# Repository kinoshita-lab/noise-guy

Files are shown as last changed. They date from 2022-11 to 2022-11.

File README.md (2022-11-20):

# noise-guy kit

[Document in Japanese](README_ja.md)

Tiny white noise generator made by ATTiny10

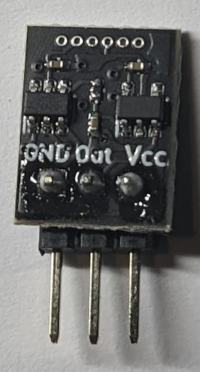
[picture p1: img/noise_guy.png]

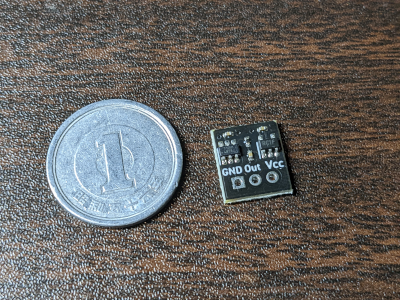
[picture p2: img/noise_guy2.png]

# Kit contents

- Pre-assembled/programmed circuit board
- 1x3 pin vertical header

# How to assemble

Solder the 1x3 pin.

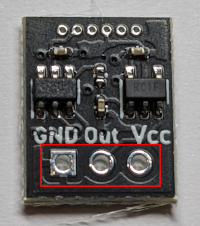
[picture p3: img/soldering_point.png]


# How to use

- Connect power source. This product use ATTiny10 with 8MHz configuration. Vcc must be within the range between 2.7V - 5.5V(cf. ATtiny10 datasheet)
- Add DC Cut capacitor to "Out" terminal externally, to meet your specification(typically 100uF - 470uF).

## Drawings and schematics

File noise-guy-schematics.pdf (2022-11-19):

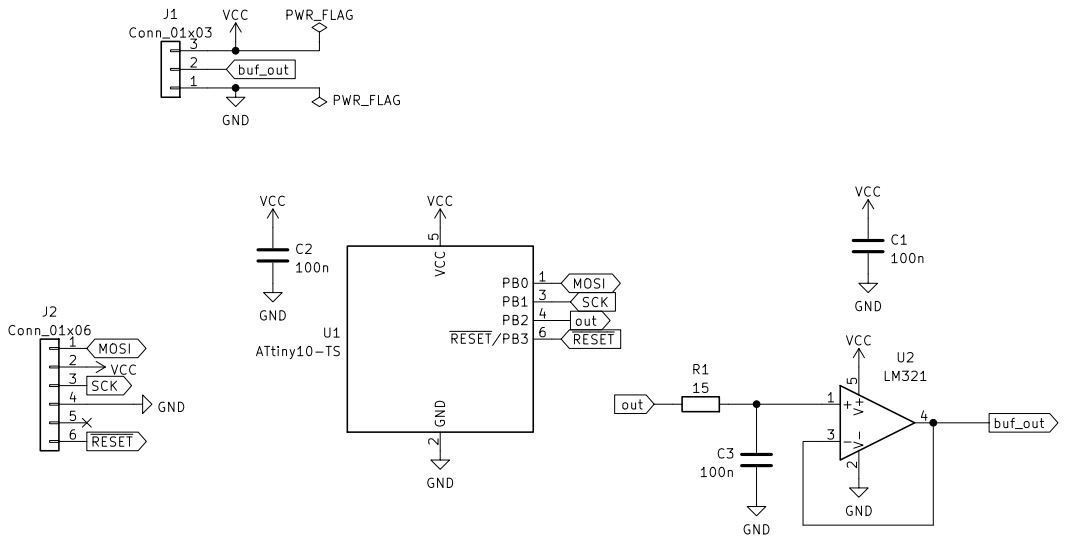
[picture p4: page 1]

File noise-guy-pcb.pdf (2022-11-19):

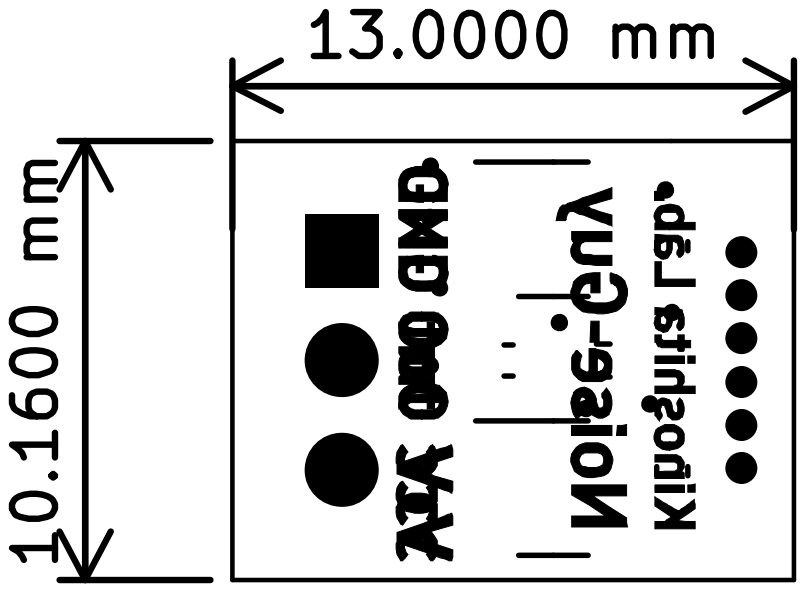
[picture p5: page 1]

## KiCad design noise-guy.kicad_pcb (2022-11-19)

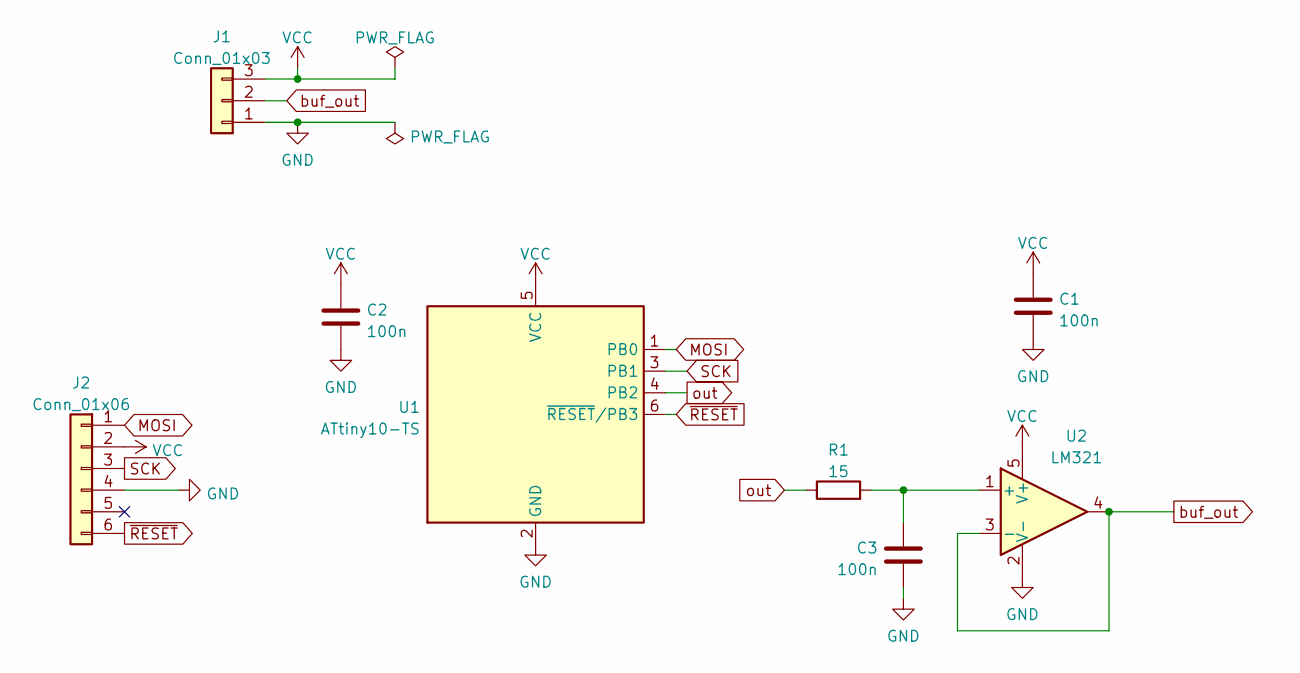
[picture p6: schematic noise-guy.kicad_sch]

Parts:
C1, C2, C3: 100n; C_0402_1005Metric; LCSC C1525
J1: Conn_01x03; PinHeader_1x03_P2.54mm_Vertical
J2: Conn_01x06; conn_01x06_attiny_JIG
R1: 15; R_0402_1005Metric; LCSC C25083
U1: ATtiny10-TS; SOT-23-6; LCSC C128438
U2: LM321; SOT-23-5; LCSC C686637

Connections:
GND: C1.2, C2.2, C3.2, J1.1, J2.4, U1.2 (GND), U2.2 (V-)
MOSI: J2.1, U1.1 (PB0)
unnamed: C3.1, R1.2, U2.1 (+)
SCK: J2.3, U1.3 (PB1)
VCC: C1.1, C2.1, J1.3, J2.2, U1.5 (VCC), U2.5 (V+)
buf_out: J1.2, U2.3 (-), U2.4
out: R1.1, U1.4 (PB2)
~RESET: J2.6, U1.6 (~RESET/PB3)

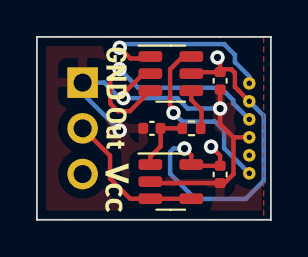
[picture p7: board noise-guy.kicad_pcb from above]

Board: 2 copper layers, 13.0 x 10.2 mm, 8 parts (0 on the bottom side), 8 nets.

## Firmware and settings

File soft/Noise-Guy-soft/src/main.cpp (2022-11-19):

// do not use platformio included avrdude!!
// avrdude -v -p attiny10 -C C:\Users\[home]\.platformio\packages\tool-avrdude\avrdude.conf -c usbasp -U flash:w:.pio\build\attiny10\firmware.hex:i

#define F_CPU 8000000UL
#include <avr/io.h>

#define sbi(PORT, BIT) PORT |= _BV(BIT)
#define cbi(PORT, BIT) PORT &= ~_BV(BIT)

uint32_t xorshift()
{
    static uint32_t v = 2463534242;
    v ^= v << 13;
    v ^= v >> 17;
    v ^= v << 5;
    return v;
}
int main()
{

    // https://electronut.in/attiny10-hello/
    // Set CPU speed by setting clock prescalar:
    // CCP register must first be written with the correct signature - 0xD8
    CCP = 0xD8;
    //  CLKPS[3:0] sets the clock division factor
    CLKPSR = 0; // 0000 (1)

    DDRB |= _BV(PB2); // set PB2 output

    for (;;) {
        const auto random = xorshift() & 0x01;
        if (random) {
            sbi(PORTB, PB2);
        } else {
            cbi(PORTB, PB2);
        }
    }
    return 0;
}

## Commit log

2022-11-19 add schematics,soft
    [noise-guy.kicad_pcb, noise-guy.kicad_sch]
2022-11-19 add pdf for schematics, pcb w/ dimension
    [noise-guy.kicad_pcb, noise-guy.kicad_sch]
